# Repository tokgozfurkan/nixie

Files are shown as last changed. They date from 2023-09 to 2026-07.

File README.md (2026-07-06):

# MSF radio controlled Nixie clock project

The firmware is written, and it compiles clean for your exact chip. Here's everything you need to know.

What I built
New sketch in code/nixieClock/nixieClock/ — three files:

nixieClock.ino — the clock: RTC-driven display, MSF sync policy, anti-poisoning, watchdog, and serial diagnostics. All configuration (pin mapping, MSF pin/polarity, sync thresholds) sits in one marked block at the top.
MSFDecoder.h / MSFDecoder.cpp — a reworked decoder (Jarkman's proven pulse logic kept). Crucially, it now uses a pin-change interrupt, because your new board wires the receiver to PC3/A3, which has no INT0/INT1 — the old library literally could not have worked on this PCB. It also hands fixes to the main loop atomically and validates every field.
Your two questions
Libraries — yes, keep them. It uses exactly what you already had: Wire (built-in) and DS3231 by Andrew Wickert (v1.2.0). The MSF decoder is your own vendored source, improved. Nothing new to install except the board package.

Memory — plenty. I compiled it for real (portable arduino-cli + MiniCore in my scratchpad, nothing installed on your system): 12,824 bytes flash (39%) and 521 bytes RAM (25%) with serial diagnostics on; 9,494 / 342 bytes with serial off. Zero compiler warnings. Roughly 60% of the chip is still free.

One flashing caveat: your BOM says ATmega328PB, not 328P. Flash via MiniCore (board: ATmega328, variant: 328PB, external 16 MHz — your BOM's crystal is 16 MHz). Plain "Uno" settings will refuse the PB's device signature.

Failure cases handled
No signal / mixed signal: a fix is only trusted after fixed-bit checks, all four parity groups, calendar sanity (including days-in-month), and two consecutive frames exactly one minute apart. A corrupted frame essentially cannot pass twice consistently. Meanwhile the DS3231 keeps time — the display never depends on reception.
Summer/winter: MSF broadcasts UK civil time with BST already applied, so changeovers arrive over the air and the clock corrects itself within ~3 minutes of good reception after the switch.
RTC lost power (no battery / first boot): the DS3231's oscillator-stop flag is checked; until the first radio sync the display blinks to say "not set" instead of showing a confident wrong time.
RTC or I²C dies at runtime: the clock freewheels on the MCU crystal (~2 s/day worst case), the bus gets a timeout plus periodic re-init, and a 4-second watchdog reboots out of any hard hang.
Nixie poisoning: hourly slot-machine cycle at xx:59:45 (~13 s, every cathode), a power-on 0–9 sweep, and a 65-minute fallback cycle while unsynced.
Accuracy: the RTC is set on a whole-second boundary of the radio epoch (a few tens of ms error), and only rewritten when it drifts ≥2 s or once per day — no needless jitter.
Bring-up (in the file header too)
Flash with ENABLE_SERIAL 1, open the monitor at 115200, send h for the command list.
Send t — each tube steps 0–9 with commentary. The TUBE_PINS[][] table is my best guess; the PDFs don't reveal the U4→U1 header order, so fix the table until tubes match the commentary.
Send m — live MSF pulse widths. You should see ~100/200/300 ms off-pulses each second and 500 ms at the minute. If not: try MSF_PIN A2 (the schematic is ambiguous between PC2/PC3), or flip MSF_PULSE_ACTIVE_HIGH.
Send i anytime for full status (signal, frames accepted/rejected, last sync age).
Two hardware flags from the schematics
I couldn't find I²C pull-up resistors on the signal board's SDA/SCL (R1/R2 are LED resistors). The AVR's weak internal pull-ups often limp along, but if the RTC reads flaky, add ~4.7 kΩ to 5 V on both lines. The code tolerates and reports a bad bus either way.
The 16-pin tube header carries only signals — make sure the two boards share a ground through the single-pin headers, or the K155ID1s will see garbage levels.
Also note: if your real tube mapping turns out to use pins 0/1 (the schematic suggests PD0/PD1 do go to the header), set ENABLE_SERIAL 0 for the final flash — the UART owns those pins while serial is active.

I went back over both schematics, the BOMs, and the firmware with a critical eye. Findings below, ordered by how likely they are to actually bite you.

Likely bring-up killers (fix these first)
1. The MSF indicator LED is loading the receiver output. On the signal board, R2 (1 kΩ) + LED hang directly on the MSF net between the Canaduino /OUT and the MCU. The MAS6180C receiver IC inside that module can only source/sink about ±0.5 mA; an LED through 1 kΩ tries to pull ~3 mA, so the line will likely clamp around the LED's forward voltage (~2 V) — below the ATmega's VIH of ~3 V at 5 V. Result: the MCU may never see a HIGH and the decoder stays silent, exactly the "no signal" failure that's hardest to diagnose. Change: remove R2/LED from the signal line. Either buffer it with a small MOSFET/transistor, or (simplest) move the LED to a spare MCU pin and let the firmware mirror the MSF input onto it — a three-line code addition I can make once the pin exists.

2. No USB-C CC pull-downs on either board. Neither BOM contains 5.1 kΩ resistors, and both Type-C connectors show CC1/CC2 without terminations. Without a 5.1 kΩ pull-down on each CC pin, a USB-C source (C-to-C cable, laptop, modern charger) will never enable VBUS — the board only powers from legacy A-to-C cables. Add: 2× 5.1 kΩ (CC1, CC2) on the combined board.

3. No 100 nF decoupling on the signal board. The signal-stage BOM has only bulk capacitance (47 µF + 10 µF) — no ceramics at the ATmega's VCC/AVCC pins or at the DS3231. Sitting next to a 160 V flyback, that's an invitation for random resets and I²C corruption. Add: 100 nF at every supply pin (MCU ×2, RTC, receiver).

4. No programming or serial access. I can't find an ISP header, a UART header, a reset pull-up, or an auto-reset circuit. MOSI/MISO/SCK and RXD/TXD all appear to run off to the tube header (U4). You can technically program through U4 plus the RST pin, but it's fragile. Add on the combined board: a 6-pin ISP header, a 10 kΩ pull-up on RESET (the internal one is weak for an environment with an HV switcher), and ideally a UART header with the DTR/100 nF auto-reset — the firmware's diagnostic commands (t, m, i) are only useful if you can reach the UART. Related: route the tube BCD lines away from PD0/PD1 when you re-layout, so serial debugging never conflicts with the display (removing the whole ENABLE_SERIAL 0 caveat in the code).

5. Crystal discrepancy. The schematic footprint says "49S13.5M…" (13.5 MHz) but the BOM part is 16 MHz. Everything — millis(), the MSF pulse classification, serial baud — assumes 16 MHz. Verify what's actually soldered; the m monitor makes it obvious (100 ms pulses would read ~118 ms with a 13.5 MHz part).

Schematic improvements for the combined board
Keep the receiver far from the flyback. A 60 kHz AM receiver next to an LT3757 switcher and USB noise is the classic nixie-clock mistake. Put the ferrite antenna at the board edge farthest from the PSU (or on a short off-board lead), add an RC filter (e.g. 100 Ω + 100 µF) on the receiver's 5 V, and keep the tube BCD traces away from it.
Route the receiver's PDN pin to an MCU pin instead of tying it off. These receivers occasionally wedge their AGC; firmware could then power-cycle the receiver if no valid frame arrives for, say, 12 hours. Cheap insurance, and I can add the code for it.
I²C pull-ups and RTC battery. If "DS3231#2" is a socket for a ZS-042-style module, the module brings its own 4.7 kΩ pull-ups and a CR2032 — fine. If you move to a bare DS3231 chip on the combined board, you must add the pull-ups, VBAT with a coin cell, and a 100 nF. Without a battery, every power cut means a blinking display until the first radio fix (~3 min at best).
Optionally route DS3231's SQW to the MCU (with a pull-up — it's open-drain). A hardware 1 Hz tick is nicer than polling if you ever add a seconds display or a blinking colon.
Consider an INS-1 neon colon between tubes 2 and 3 (spare MCU pin + high-voltage transistor + ~220 kΩ from 160 V). Cosmetic, but it also gives a visible "alive" heartbeat.
Ground between the boards: the 16-pin tube header carries no GND, so the prototype pair depends entirely on the single-pin jumpers. Add several ground pins next to the signal lines (or just let the combined board solve it).
Flyback margins: the IRLR3110 (100 V) sees 5 V + ~16 V reflected + the leakage-inductance spike, and there's no snubber. The DA2032 has low leakage so it's probably fine, but scope the drain on first power-up; add an RC snubber footprint just in case. The feedback divider (1 M + pot) doubles as an HV bleeder, which is good. Add an HV warning on the silkscreen.
Two things that look wrong but are actually fine: the K155ID1's TTL inputs float HIGH when the MCU resets or the header is unplugged, which reads as BCD 15 → tubes blank during reset/programming — a happy accident worth keeping; and the 10 k anode resistors give ~2 mA per IN-12A, slightly conservative but adjustable via the pot.
Code improvements
Honest self-review of nixieClock.ino and the decoder:

Add the MSF activity LED mirror (one output pin, set in handleEdge or the display loop) once the hardware LED moves off the signal line — restores the blink-per-second feedback the board intended, without loading the receiver.
Add receiver power-cycling via PDN if you route it: "no confirmed fix in 12 h → pulse PDN" plus a counter in the status output.
RTC reads are 6 separate I²C transactions every 500 ms. Works, but a single burst read of registers 0x00–0x06 would be more atomic (no risk of reading minutes just as they roll over — currently a roll-over between getMinute() and getHour() could produce a one-off time that's wrong by an hour for half a second; the next 500 ms poll self-corrects, and the display only shows HH:MM, but a burst read removes the race entirely). This is the one genuine, if minor, correctness improvement I'd make in the current code.
applyFix blocks up to ~1 s spinning to the second boundary. Documented and harmless (sync happens at most daily), but if you ever add a seconds display it should become non-blocking.
Leap seconds are handled by rejection: a 61-bit minute fails the bitIndex == 60 check, the frame is discarded, and the next minute syncs normally. No change needed — just noting it's covered.
PULSE_OFF_OFFSET 20 is tuned for Jarkman's 2011 receiver, not the Canaduino. Use the m monitor on real hardware: if the off-widths cluster at, say, 95/195/295 you can drop it to 0. Worth re-checking rather than trusting the inherited constant.
Optional feature, since you skipped night blanking: duty-cycle dimming is nearly free with the K155ID1 (alternate digit/TUBE_BLANK at a few hundred Hz), which would allow night dimming and extend tube life without fully blanking.
The one thing I'd remove: nothing in the firmware, but on the hardware side the second USB-C connector disappears in the combined design, and R2+LED should come off the MSF line as described.

If you want, I can implement the firmware-side items now (burst RTC read, LED mirror pin, PDN control behind a #define so they're inert until the hardware exists) — say the word.

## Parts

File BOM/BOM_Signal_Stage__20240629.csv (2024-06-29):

LCSC Part Number | Manufacture Part Number | Manufacturer | Customer NO. | Package | Description | RoHS | Order Qty. | Min\Mult Order Qty. | Unit Price($) | Order Price($)
C2875465 | 0603N220J500CT | Walsin Tech Corp |  | 0603 | 50V 22pF NP0 ±5% 0603 Multilayer Ceramic Capacitors MLCC - SMD/SMT ROHS | YES | 100 | 100\100 | 0.003 | 0.30
C7496820 | F.0603.00139/P2-0603R1TS2-06T-002 | TUOZHAN |  | 0603 | 5mA -40℃~+85℃ Red 120° 0603 Light Emitting Diodes (LED) ROHS | YES | 100 | 100\100 | 0.0032 | 0.32
C132230 | ATMEGA328PB-AU | Microchip Tech |  | TQFP-32(7x7) | 32KB 1.8V~5.5V AVR 2KB 20MHz FLASH 27 TQFP-32(7x7) Microcontroller Units (MCUs/MPUs/SOCs) ROHS | YES | 2 | 1\1 | 1.8028 | 3.61
C5265724 | HY16M49SOB2T02 | Huiyuan crystal |  | HC-49S | 16MHz 20pF ±20ppm ±50ppm HC-49S Crystals ROHS | YES | 10 | 10\10 | 0.0342 | 0.34
C2907113 | FRC0603J102 TS | FOJAN |  | 0603 | 100mW Thick Film Resistors 75V ±100ppm/℃ ±5% 1kΩ 0603 Chip Resistor - Surface Mount ROHS | YES | 100 | 100\100 | 0.0008 | 0.08
C5146764 | X5511FV-04-C30D743-0743 | XKB Connection |  | - | 2.54mm Plugin 4P 1x4P 3mm Circular Holes - Female Headers ROHS | YES | 10 | 5\5 | 0.0715 | 0.72

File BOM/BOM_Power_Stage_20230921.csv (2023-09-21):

LCSC Part Number | Manufacture Part Number | Manufacturer | Customer NO. | Package | Description | RoHS | Order Qty. | Min\Mult Order Qty. | Unit Price | Order Price
C382228 | FM31X223K631EEG | PSA(Prosperity Dielectrics) |  | 1206 | 630V 22nF X7R ±10% 1206 Multilayer Ceramic Capacitors MLCC - SMD/SMT ROHS | YES | 50 | 50\50 | 0.008400 | 0.42
C976240 | FM31X224K251EEG | PSA(Prosperity Dielectrics) |  | 1206 | 250V 220nF ±10% 1206 Multilayer Ceramic Capacitors MLCC - SMD/SMT ROHS | YES | 20 | 20\20 | 0.020000 | 0.40
C1884 | 1206CG101J500NT | FH (Guangdong Fenghua Advanced Tech) |  | 1206 | 50V 100pF C0G ±5% 1206 Multilayer Ceramic Capacitors MLCC - SMD/SMT ROHS | YES | 50 | 50\50 | 0.011500 | 0.58
C7467448 | FRL2512JR020TS | FOJAN |  | 2512 | 1W Thick Film Resistors 1200ppm/℃ ±5% 20mΩ 2512 Chip Resistor - Surface Mount ROHS | YES | 10 | 10\10 | 0.039000 | 0.39
C67277 | IRLR3110ZTRPBF | Infineon Technologies |  | TO-252-2(DPAK) | 100V 42A 140W 14mΩ@10V,38A N Channel TO-252-2(DPAK) MOSFETs ROHS | YES | 10 | 1\1 | 0.989600 | 9.90
C464972 | FN31X104K500PXG | PSA(Prosperity Dielectrics) |  | 1206 | 50V 100nF X7R ±10% 1206 Multilayer Ceramic Capacitors MLCC - SMD/SMT ROHS | YES | 50 | 50\50 | 0.006100 | 0.31
C229316 | AC1206FR-07140KL | YAGEO |  | 1206 | 250mW Thick Film Resistors ±100ppm/℃ ±1% 140kΩ 1206 Chip Resistor - Surface Mount ROHS | YES | 50 | 50\50 | 0.004400 | 0.22
C2918513 | CS3225X5R476K160NRL | Samwha Capacitor |  | 1210 | 16V 47uF X5R ±10% 1210 Multilayer Ceramic Capacitors MLCC - SMD/SMT ROHS | YES | 25 | 5\5 | 0.095800 | 2.40
C280037 | CR-06JL7----1M | Viking Tech |  | 1206 | 250mW Thick Film Resistors ±5% 1MΩ 1206 Chip Resistor - Surface Mount ROHS | YES | 50 | 50\50 | 0.002400 | 0.12
C280031 | CR-06JL7----0R | Viking Tech |  | 1206 | 250mW Thick Film Resistors ±5% 0Ω 1206 Chip Resistor - Surface Mount ROHS | YES | 50 | 50\50 | 0.002400 | 0.12
C93059 | 1206X106M250NT | FH (Guangdong Fenghua Advanced Tech) |  | 1206 | 25V 10uF X5R ±20% 1206 Multilayer Ceramic Capacitors MLCC - SMD/SMT ROHS | YES | 10 | 10\10 | 0.017900 | 0.18
C128545 | VG039NCHXTB104 | HDK(Hokuriku Elec Industry) |  | SMD | ±25% 100kΩ SMD Variable Resistors/Potentiometers ROHS | YES | 10 | 10\10 | 0.079500 | 0.80
C5274471 | KH-SS12F44-G3.5 | Shenzhen Kinghelm Elec |  | Plugin | Plugin Slide Switches ROHS | YES | 10 | 10\10 | 0.023100 | 0.23
C104602 | RTT06103JTP | RALEC |  | 1206 | 250mW ±100ppm/℃ ±5% 10kΩ 1206 Chip Resistor - Surface Mount ROHS | YES | 100 | 100\100 | 0.002200 | 0.22
C456012 | TYPE-C 6P | SHOU HAN |  | SMD | 1 Surface Mount 6P Female -40℃~+85℃ Type-C SMD USB Connectors ROHS | YES | 10 | 10\10 | 0.043600 | 0.44
C881297 | CR1206J22R0P05Z | Ever Ohms Tech |  | 1206 | 250mW ±100ppm/℃ ±5% 22Ω 1206 Chip Resistor - Surface Mount ROHS | YES | 50 | 50\50 | 0.002300 | 0.12
C962640 | RFN1LAM6STR | ROHM Semicon |  | SOD-128 | 1.15V@800mA 25ns Single 800mA 600V SOD-128 Diodes - Fast Recovery Rectifiers ROHS | YES | 10 | 1\1 | 0.087900 | 0.88
C81276 | C81276 | BOOMELE(Boom Precision Elec) |  | Plugin,P=2.54mm | Straight 1P Plugin Black Plugin,P=2.54mm Pin Headers ROHS | YES | 100 | 100\100 | 0.006600 | 0.66
C5153981 | FRC1206F6342TS | FOJAN |  | 1206 | 250mW Thick Film Resistors ±100ppm/℃ ±1% 63.4kΩ 1206 Chip Resistor - Surface Mount ROHS | YES | 10 | 5\5 | 0.002900 | 0.03

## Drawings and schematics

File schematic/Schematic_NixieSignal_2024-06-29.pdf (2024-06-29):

A | A
B | B

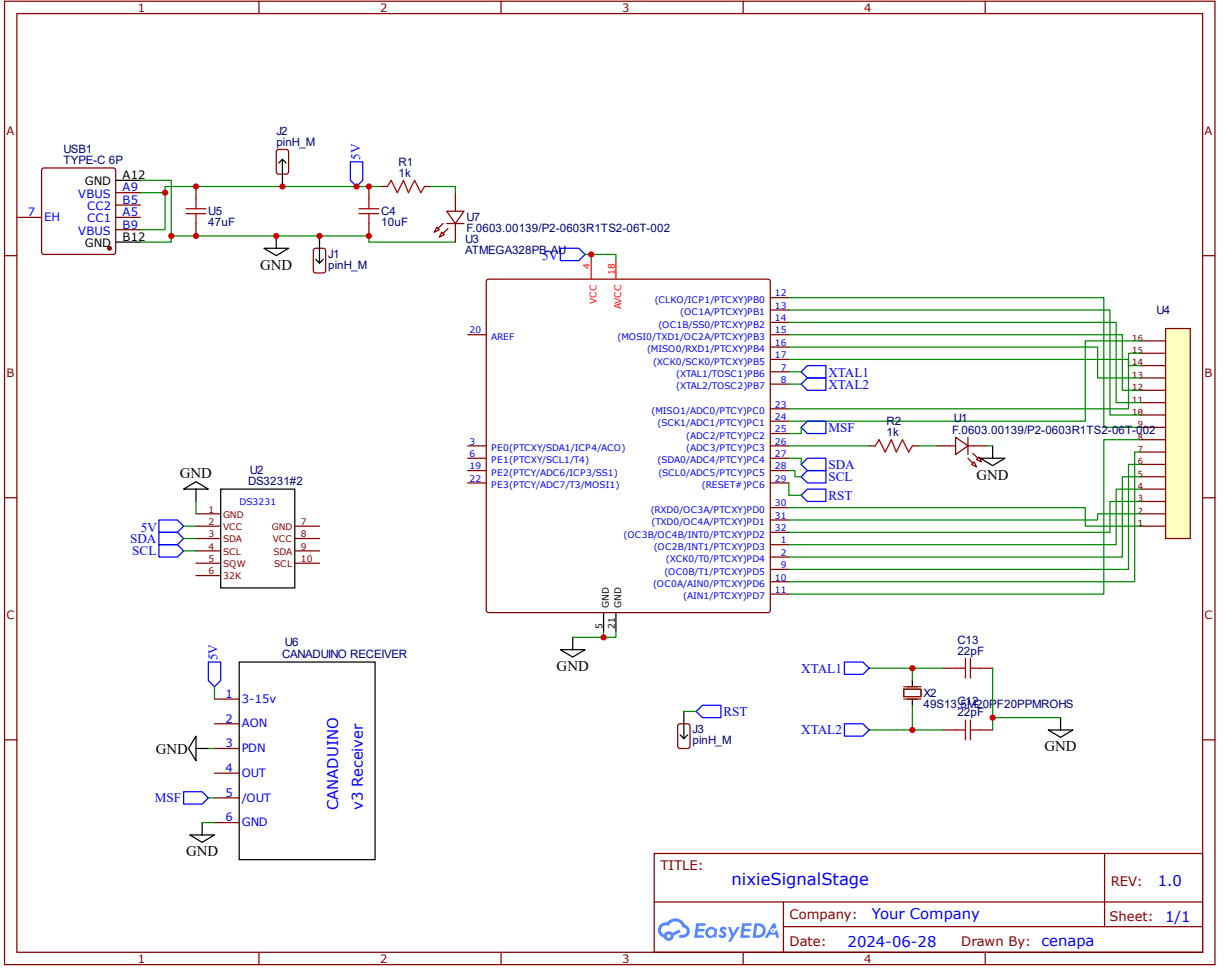
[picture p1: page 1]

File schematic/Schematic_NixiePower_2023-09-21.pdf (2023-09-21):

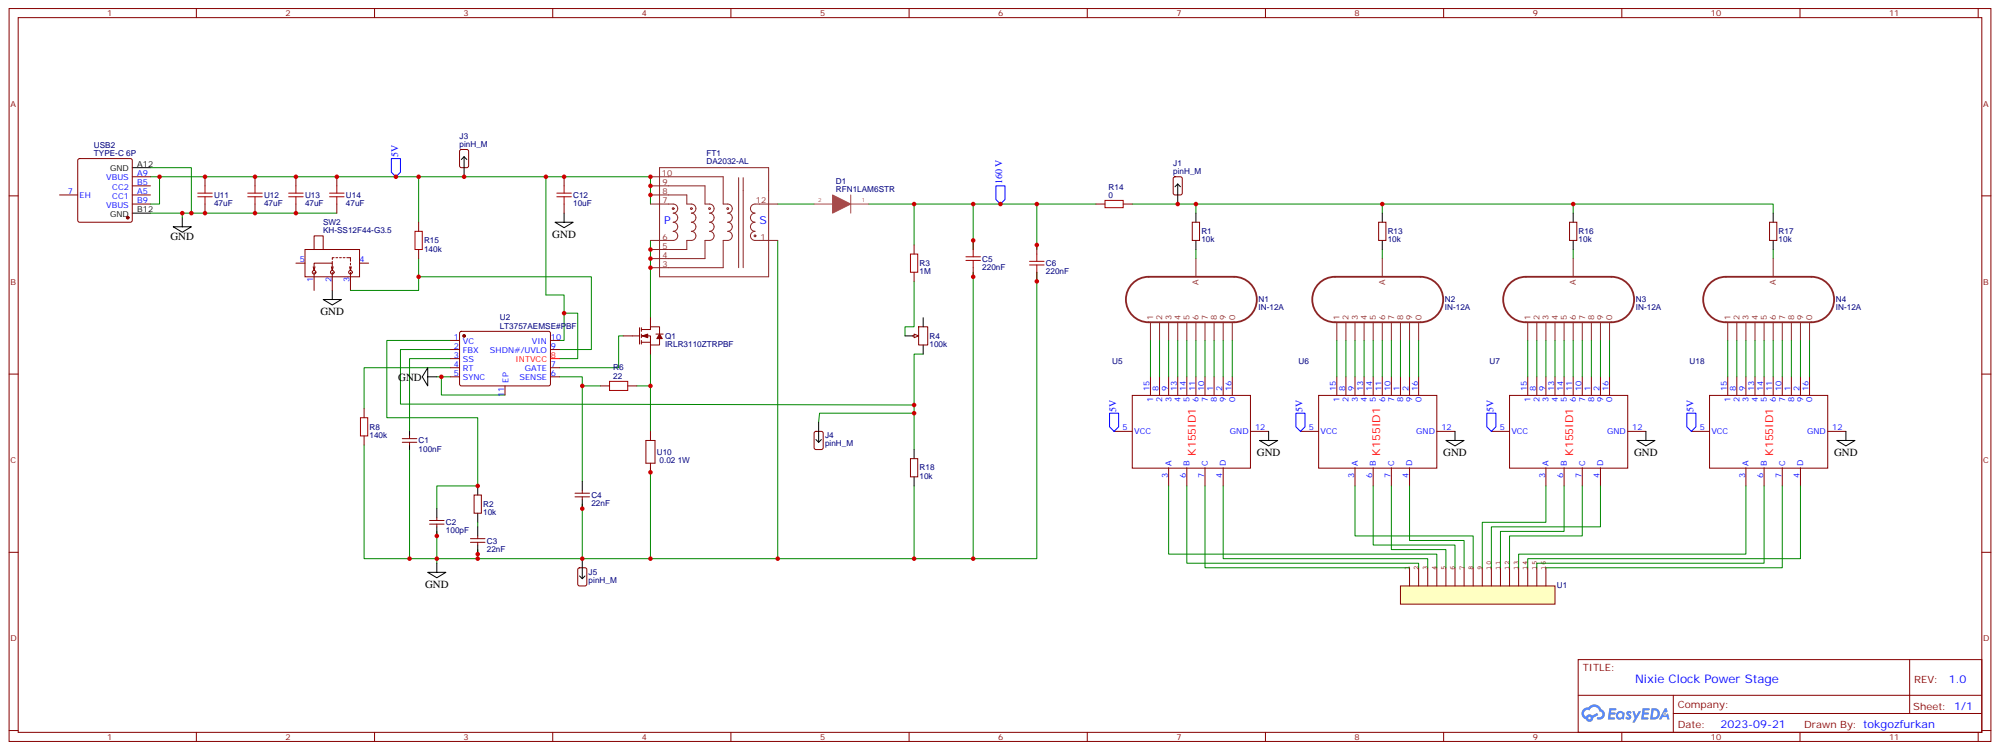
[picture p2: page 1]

10

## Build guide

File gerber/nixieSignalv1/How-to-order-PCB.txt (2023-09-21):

How to Order PCB

Please refer to:
https://docs.easyeda.com/en/PCB/Order-PCB

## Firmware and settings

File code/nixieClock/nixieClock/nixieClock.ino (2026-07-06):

/*
  nixieClock — MSF-synchronised IN-12A nixie clock
  =================================================

  Hardware (this repo):
    * Signal board: ATmega328PB @ 16 MHz, DS3231 RTC on I2C (A4/A5),
      Canaduino v3 MSF receiver with its inverted /OUT wired to the MCU
      (assumed A3/PC3 — see MSF_PIN), 16-pin header carrying 4x4 BCD
      lines to the power board.
    * Power board: LT3757 flyback boost to 160 V, 4x IN-12A tubes, each
      behind a K155ID1 BCD decoder. Any BCD input > 9 blanks that tube,
      which this code uses for blanking (TUBE_BLANK).

  Behaviour:
    * The DS3231 is the timekeeper; the display is always driven from it.
    * The MSF decoder runs continuously via a pin-change interrupt. A time
      fix is only trusted after: fixed-bit check + all four parity groups
      + calendar sanity + TWO consecutive frames exactly one minute apart
      (defeats corrupted/mixed reception). The RTC is then set to within
      a few tens of ms of the radio second.
    * The RTC is only rewritten when it disagrees with the radio by >= 2 s
      or at most once per 24 h. Summer/winter changes arrive over the air
      (MSF broadcasts UK civil time) and are corrected within ~3 minutes
      of good reception after the change.
    * If the RTC stops responding, the clock freewheels on the MCU crystal
      (~20 ppm) until it returns. If the time has never been trusted (RTC
      lost power and no radio sync yet) the display blinks while counting,
      to say "not set".
    * Anti-poisoning: once per hour at xx:59:45 a ~13 s slot-machine cycle
      exercises every cathode of every tube; a fallback cycle runs every
      65 min if the time is not set.
    * A 4 s watchdog recovers from any hang; I2C has a bus timeout.

  Flashing (IMPORTANT — the chip is an ATmega328PB, not a plain 328P):
    * Install MiniCore in the Arduino IDE boards manager:
      https://mcudude.github.io/MiniCore/package_MCUdude_MiniCore_index.json
    * Board: ATmega328 / Variant: 328PB / Clock: external 16 MHz.
    * Libraries: Wire (built in) and "DS3231" by Andrew Wickert
      (NorthernWidget) — the same one the earlier sketches used.

  Bring-up checklist:
    1. Flash with ENABLE_SERIAL 1, open Serial Monitor @ 115200, send 'h'.
    2. Send 't': each tube steps through 0..9 with serial commentary.
       Correct TUBE_PINS[][] below until the tubes match the commentary.
    3. Send 'm': raw MSF pulse monitor. With reception you should see one
       off-pulse per second near 100/200/300 ms (500 ms once a minute).
       If the widths look inverted (~700-900 ms), flip
       MSF_PULSE_ACTIVE_HIGH. If nothing arrives, try MSF_PIN A2 — the
       schematic is ambiguous between PC2 and PC3.
    4. Give it 2-5 min of good reception: you should see "MSF frame ok"
       and then "RTC set from MSF".
    5. If your final TUBE_PINS mapping uses pins 0/1 (the UART pins), set
       ENABLE_SERIAL 0 for the production flash — while serial is enabled
       the UART owns those pins and two BCD lines would misbehave.
*/

#include <Wire.h>
#include <DS3231.h>
#include <avr/wdt.h>
#include "MSFDecoder.h"

// ============================ CONFIGURATION ============================

#define ENABLE_SERIAL   1       // set 0 for the final flash if TUBE_PINS uses pins 0/1
#define ENABLE_WATCHDOG 1       // needs a modern bootloader (MiniCore is fine)
#define SERIAL_BAUD     115200

#define MSF_PIN               A3    // PC3 per schematic; try A2 if silent
#define MSF_PULSE_ACTIVE_HIGH true  // /OUT: HIGH while the carrier is off
// If you move MSF_PIN off the A0-A5 port, also change MSF_PCINT_VECTOR
// in MSFDecoder.h (PCINT0_vect for D8-D13, PCINT2_vect for D0-D7).

// MCU pin -> K155ID1 BCD input mapping, one row per tube, left to right.
// Columns are {A, B, C, D} = binary weights {1, 2, 4, 8} (K155ID1 pins
// 3, 6, 7, 4). *** BEST GUESS — verify with the 't' serial command and
// edit this table until the tubes match the commentary. ***
const uint8_t TUBE_PINS[4][4] = {
  {  8,  9, 10, 11 }, // tube 1: hour tens    (PB0..PB3)
  { 12, 13, A0, A1 }, // tube 2: hour units   (PB4, PB5, PC0, PC1)
  {  0,  1,  2,  3 }, // tube 3: minute tens  (PD0..PD3)
  {  4,  5,  6,  7 }, // tube 4: minute units (PD4..PD7)
};

#define TUBE_BLANK 0x0F  // any BCD value > 9 turns all K155ID1 outputs off

const int32_t  SYNC_THRESHOLD_S    = 2;              // rewrite RTC if off by this much
const uint32_t RESYNC_INTERVAL_MS  = 86400000UL;     // ... or at least daily
const uint8_t  POISON_MINUTE       = 59;             // hourly cycle at xx:59:45
const uint8_t  POISON_SECOND      = 45;
const uint32_t POISON_DURATION_MS  = 13000UL;
const uint32_t POISON_FALLBACK_MS  = 65UL * 60UL * 1000UL; // if time never set

// =======================================================================

DS3231     rtc;
MSFDecoder msf;

struct ClockTime
{
  uint8_t y;   // 0-99 (20xx)
  uint8_t mo;  // 1-12
  uint8_t d;   // 1-31
  uint8_t h;   // 0-23
  uint8_t mi;  // 0-59
  uint8_t s;   // 0-59
};

// The "soft clock": a RAM copy of the current time, re-anchored from the
// RTC every 500 ms and ticked from millis() so it freewheels if the RTC
// or the I2C bus dies.
ClockTime     softTime = {0, 1, 1, 0, 0, 0};
unsigned long softAnchor = 0;

bool    rtcResponding = false;  // recent I2C reads succeeded
bool    rtcTrusted    = false;  // responding AND oscillator-stop flag clear
uint8_t rtcFailCount  = 0;

bool          everSynced    = false;  // at least one MSF sync this power-up
unsigned long lastSyncMillis = 0;

bool          havePrevFix   = false;  // MSF double-frame confirmation chain
uint32_t      prevFixMin    = 0;
unsigned long prevFixMillis = 0;

bool          poisonActive     = false;
unsigned long poisonStart      = 0;
unsigned long lastPoisonMillis = 0;

// ---------------------------- date helpers ----------------------------
// Valid for 2000-2099 (every year divisible by 4 is a leap year there).

uint8_t daysInMonth(uint8_t y, uint8_t mo)
{
  static const uint8_t dim[12] = {31, 28, 31, 30, 31, 30, 31, 31, 30, 31, 30, 31};
  uint8_t n = dim[mo - 1];
  if (mo == 2 && (y & 3) == 0) n++;
  return n;
}

uint16_t days2000(uint8_t y, uint8_t mo, uint8_t d)
{
  static const uint16_t cum[12] = {0, 31, 59, 90, 120, 151, 181, 212, 243, 273, 304, 334};
  uint16_t days = (uint16_t)y * 365 + (y + 3) / 4 + cum[mo - 1] + (d - 1);
  if (mo > 2 && (y & 3) == 0) days++;
  return days;
}

uint32_t minutes2000(const MSFTime &f)
{
  return (uint32_t)days2000(f.year, f.month, f.day) * 1440UL
       + (uint32_t)f.hour * 60UL + f.minute;
}

uint32_t secs2000(const ClockTime &t)
{
  return (uint32_t)days2000(t.y, t.mo, t.d) * 86400UL
       + (uint32_t)t.h * 3600UL + (uint32_t)t.mi * 60UL + t.s;
}

void addSeconds(ClockTime &t, uint32_t secs)
{
  uint32_t v = t.s + secs;
  t.s = v % 60; v /= 60;
  v += t.mi;
  t.mi = v % 60; v /= 60;
  v += t.h;
  t.h = v % 24; v /= 24;
  while (v--)
  {
    if (++t.d > daysInMonth(t.y, t.mo))
    {
      t.d = 1;
      if (++t.mo > 12) { t.mo = 1; if (++t.y > 99) t.y = 0; }
    }
  }
}

// ---------------------------- tube driving ----------------------------

void setTube(uint8_t tube, uint8_t value)
{
  for (uint8_t b = 0; b < 4; b++)
    digitalWrite(TUBE_PINS[tube][b], (value >> b) & 1);
}

void blankAll()
{
  for (uint8_t t = 0; t < 4; t++) setTube(t, TUBE_BLANK);
}

void showTime(uint8_t h, uint8_t mi)
{
  setTube(0, h / 10);
  setTube(1, h % 10);
  setTube(2, mi / 10);
  setTube(3, mi % 10);
}

// ------------------------------- RTC ----------------------------------

bool timeValid()
{
  // Trust the RTC when its oscillator never stopped; if the RTC has died
  // but we synced from the radio this power-up, the freewheeling soft
  // clock is still good.
  return rtcTrusted || (everSynced && !rtcResponding);
}

bool readRTC(ClockTime &t)
{
  bool h12, pm, century;
  t.s  = rtc.getSecond();
  t.mi = rtc.getMinute();
  t.h  = rtc.getHour(h12, pm);
  t.d  = rtc.getDate();
  t.mo = rtc.getMonth(century);
  t.y  = rtc.getYear();
  // A dead/absent bus yields out-of-range BCD; treat anything insane as a
  // failed read so the soft clock freewheels instead of jumping.
  if (t.s > 59 || t.mi > 59 || t.h > 23 || t.y > 99) return false;
  if (t.mo < 1 || t.mo > 12 || t.d < 1 || t.d > daysInMonth(t.y, t.mo)) return false;
  return true;
}

void serviceRTC(bool force)
{
  static unsigned long last = 0;
  if (!force && millis() - last < 500UL) return;
  last = millis();

  ClockTime t;
  if (readRTC(t))
  {
    rtcFailCount  = 0;
    rtcResponding = true;
    rtcTrusted    = rtc.oscillatorCheck(); // false if the RTC ever lost power
    softTime      = t;
    softAnchor    = millis();
  }
  else
  {
    if (rtcFailCount < 250) rtcFailCount++;
    if (rtcFailCount >= 6) { rtcResponding = false; rtcTrusted = false; }
    if (rtcFailCount % 20 == 0)
    {
      Wire.begin(); // try to recover a wedged bus
#if defined(WIRE_HAS_TIMEOUT)
      Wire.setWireTimeout(25000, true);
      Wire.clearWireTimeoutFlag();
#endif
    }
  }
}

void serviceSoftClock()
{
  while (millis() - softAnchor >= 1000UL)
  {
    softAnchor += 1000UL;
    addSeconds(softTime, 1);
  }
}

// ------------------------------- MSF ----------------------------------

#if ENABLE_SERIAL
void print2(uint8_t v)
{
  if (v < 10) Serial.print('0');
  Serial.print(v);
}

void printClock(const ClockTime &t)
{
  Serial.print(F("20")); print2(t.y);
  Serial.print('-'); print2(t.mo);
  Serial.print('-'); print2(t.d);
  Serial.print(' '); print2(t.h);
  Serial.print(':'); print2(t.mi);
  Serial.print(':'); print2(t.s);
}
#endif

// Write a confirmed radio fix into the RTC, aligned to the second.
void applyFix(const MSFTime &f, unsigned long fixMillis)
{
  // Spin (max ~1 s) to a whole-second boundary of the radio epoch so the
  // DS3231's internal second-countdown restarts in phase with the signal.
  unsigned long el;
  do {
#if ENABLE_WATCHDOG
    wdt_reset();
#endif
    el = millis() - fixMillis;
  } while (el % 1000UL > 30UL);

  ClockTime t = { f.year, f.month, f.day, f.hour, f.minute, 0 };
  uint16_t d0 = days2000(t.y, t.mo, t.d);
  addSeconds(t, el / 1000UL);
  uint8_t dow = (f.dow + (uint8_t)(days2000(t.y, t.mo, t.d) - d0)) % 7;

  rtc.setClockMode(false); // 24 h
  rtc.setYear(t.y);
  rtc.setMonth(t.mo);
  rtc.setDate(t.d);
  rtc.setDoW(dow + 1);     // 1 = Sunday
  rtc.setHour(t.h);
  rtc.setMinute(t.mi);
  rtc.setSecond(t.s);      // written last; also clears the oscillator-stop flag

  softTime   = t;
  softAnchor = millis() - (el % 1000UL);

#if ENABLE_SERIAL
  Serial.print(F("RTC set from MSF: "));
  printClock(t);
  Serial.println(f.summer ? F(" (BST)") : F(" (GMT)"));
#endif
}

void serviceMSF()
{
  MSFTime f;
  unsigned long tf;
  if (!msf.takeFix(f, tf)) return;

  uint32_t fixMin = minutes2000(f);

  // Require two consecutive frames exactly one minute apart before
  // touching the RTC — a corrupted frame that beat the parity checks
  // will practically never do so twice in a row *and* be consistent.
  bool confirmed = false;
  if (havePrevFix)
  {
    unsigned long gap = tf - prevFixMillis;
    confirmed = (gap >= 59000UL && gap <= 61000UL) && (fixMin == prevFixMin + 1);
  }
  havePrevFix   = true;
  prevFixMin    = fixMin;
  prevFixMillis = tf;

#if ENABLE_SERIAL
  Serial.print(F("MSF frame ok: 20")); print2(f.year);
  Serial.print('-'); print2(f.month);
  Serial.print('-'); print2(f.day);
  Serial.print(' '); print2(f.hour);
  Serial.print(':'); print2(f.minute);
  Serial.println(confirmed ? F(" [confirmed]") : F(" [waiting for 2nd frame]"));
#endif

  if (!confirmed) return;

  uint32_t msfNow = fixMin * 60UL + (millis() - tf) / 1000UL;
  int32_t  diff   = (int32_t)(msfNow - secs2000(softTime));

  bool need = !timeValid()
           || diff >= SYNC_THRESHOLD_S || diff <= -SYNC_THRESHOLD_S
           || !everSynced
           || (millis() - lastSyncMillis) >= RESYNC_INTERVAL_MS;
  if (need) applyFix(f, tf);

  // Even when no rewrite was needed, the radio just vouched for the RTC.
  everSynced     = true;
  lastSyncMillis = millis();
}

// --------------------------- anti-poisoning ---------------------------

void startPoison()
{
  poisonActive = true;
  poisonStart  = millis();
}

void servicePoison()
{
  if (poisonActive)
  {
    if (millis() - poisonStart >= POISON_DURATION_MS)
    {
      poisonActive     = false;
      lastPoisonMillis = millis();
    }
    return;
  }
  if (timeValid() && softTime.mi == POISON_MINUTE && softTime.s == POISON_SECOND)
    startPoison();
  else if (millis() - lastPoisonMillis >= POISON_FALLBACK_MS)
    startPoison(); // keeps cathodes exercised even while unsynchronised
}

// ------------------------------ display -------------------------------

void serviceDisplay()
{
  if (poisonActive)
  {
    uint16_t step = (uint16_t)((millis() - poisonStart) / 70UL);
    for (uint8_t t = 0; t < 4; t++)
      setTube(t, (step + t * 3) % 10);
    return;
  }

  bool show = true;
  if (!timeValid()) show = (millis() % 1000UL) < 700UL; // blink = "not set"

  if (show) showTime(softTime.h, softTime.mi);
  else      blankAll();
}

// ------------------------- serial diagnostics -------------------------

#if ENABLE_SERIAL

void printHelp()
{
  Serial.println(F("Commands: i=status  t=tube mapping test  m=MSF pulse monitor (30s)  p=poison cycle now  h=help"));
}

void printStatus()
{
  Serial.println(F("--- nixieClock status ---"));
  Serial.print(F("Soft time : ")); printClock(softTime); Serial.println();
  Serial.print(F("Time valid: ")); Serial.println(timeValid() ? F("yes") : F("no (display blinking)"));
  Serial.print(F("RTC       : "));
  Serial.print(rtcResponding ? F("responding") : F("NOT RESPONDING"));
  Serial.print(F(", oscillator "));
  Serial.println(rtcTrusted ? F("ok") : F("stopped at some point (untrusted until sync)"));
  Serial.print(F("MSF       : signal "));
  Serial.print(msf.hasSignal() ? F("yes") : F("NO"));
  Serial.print(F(", frame bit ")); Serial.print(msf.bitCount());
  Serial.print(F(", valid frames ")); Serial.print(msf.goodFixes());
  Serial.print(F(", rejected ")); Serial.println(msf.rejects());
  Serial.print(F("Last sync : "));
  if (everSynced)
  {
    Serial.print((millis() - lastSyncMillis) / 60000UL);
    Serial.println(F(" min ago"));
  }
  else Serial.println(F("never (this power-up)"));
}

// Steps every tube through 0..9 so TUBE_PINS[][] can be verified.
void tubeTest()
{
  while (Serial.available()) Serial.read();
  Serial.println(F("Tube mapping test — press any key to abort."));
  for (uint8_t t = 0; t < 4 && !Serial.available(); t++)
  {
    blankAll();
    for (uint8_t v = 0; v < 10 && !Serial.available(); v++)
    {
      setTube(t, v);
      Serial.print(F("Tube ")); Serial.print(t + 1);
      Serial.print(F(" (row ")); Serial.print(t);
      Serial.print(F(" of TUBE_PINS) should show ")); Serial.println(v);
      unsigned long t0 = millis();
      while (millis() - t0 < 800UL && !Serial.available())
      {
#if ENABLE_WATCHDOG
        wdt_reset();
#endif
      }
    }
  }
  while (Serial.available()) Serial.read();
  blankAll();
  Serial.println(F("Test done. If digits were wrong, edit TUBE_PINS[][] and reflash."));
}

// Prints every classified MSF pulse for 30 s.
void msfMonitor()
{
  while (Serial.available()) Serial.read();
  Serial.println(F("MSF pulse monitor for 30 s (off ~100/200/300, 500=minute marker) — any key to abort."));
  uint16_t lastCount;
  noInterrupts(); lastCount = msf.dbgPulseCount; interrupts();
  unsigned long t0 = millis();
  while (millis() - t0 < 30000UL && !Serial.available())
  {
#if ENABLE_WATCHDOG
    wdt_reset();
#endif
    int16_t off, on;
    uint16_t count;
    noInterrupts();
    off = msf.dbgOffWidth; on = msf.dbgOnWidth; count = msf.dbgPulseCount;
    interrupts();
    if (count != lastCount)
    {
      lastCount = count;
      Serial.print(F("off=")); Serial.print(off);
      Serial.print(F(" ms, on=")); Serial.print(on);
      Serial.print(F(" ms, frame bit ")); Serial.println(msf.bitCount());
    }
  }
  while (Serial.available()) Serial.read();
  Serial.println(F("Monitor done."));
}

void serviceSerial()
{
  if (!Serial.available()) return;
  char c = Serial.read();
  switch (c)
  {
    case 'i': printStatus(); break;
    case 't': tubeTest();    break;
    case 'm': msfMonitor();  break;
    case 'p': startPoison(); break;
    case 'h':
    case '?': printHelp();   break;
    default:  break; // ignore line endings etc.
  }
}

#endif // ENABLE_SERIAL

// ------------------------------- setup --------------------------------

void setup()
{
  MCUSR = 0;      // make sure a watchdog reset can't turn into a boot loop
  wdt_disable();

  for (uint8_t t = 0; t < 4; t++)
    for (uint8_t b = 0; b < 4; b++)
      pinMode(TUBE_PINS[t][b], OUTPUT);
  blankAll();

#if ENABLE_SERIAL
  Serial.begin(SERIAL_BAUD);
  Serial.println(F("nixieClock starting"));
  printHelp();
#endif

  Wire.begin();
#if defined(WIRE_HAS_TIMEOUT)
  Wire.setWireTimeout(25000, true); // never let a stuck bus hang the loop
#endif

  msf.begin(MSF_PIN, MSF_PULSE_ACTIVE_HIGH);

  // power-on sweep: proves every cathode of every tube works
  for (uint8_t v = 0; v < 10; v++)
  {
    for (uint8_t t = 0; t < 4; t++) setTube(t, v);
    delay(180);
  }
  blankAll();

  softAnchor       = millis();
  lastPoisonMillis = millis();
  serviceRTC(true); // adopt battery-backed RTC time immediately if sane

#if ENABLE_SERIAL
  Serial.print(F("Boot time from RTC: "));
  printClock(softTime);
  Serial.println(rtcTrusted ? F(" (trusted)") : F(" (NOT trusted — waiting for MSF)"));
#endif

#if ENABLE_WATCHDOG
  wdt_enable(WDTO_4S);
#endif
}

void loop()
{
#if ENABLE_WATCHDOG
  wdt_reset();
#endif
  serviceSoftClock();
  serviceRTC(false);
  serviceMSF();
  servicePoison();
  serviceDisplay();
#if ENABLE_SERIAL
  serviceSerial();
#endif
}

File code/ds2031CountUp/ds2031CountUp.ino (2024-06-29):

/*

Sets the time from input and prints back time stamps for 5 seconds

Based on DS3231_set.pde
by Eric Ayars
4/11

Added printing back of time stamps and increased baud rate
(to better synchronize computer and RTC)
Andy Wickert
5/15/2011

Clean for SAMD arch, add explanation, respect code-style and
fix interpretation of Serial input if used more than once
Olivier Staquet
4/26/2020

*/

#include <DS3231.h>
#include <Wire.h>

DS3231 myRTC;

byte year;
byte month;
byte date;
byte dow;
byte hour;
byte minute;
byte second;

bool century = false;
bool h12Flag;
bool pmFlag;

// Nixie tube pins
int segmentPins[1][4] = {
  {11,10,9,8},   // Tube 1
};

// Nixie tube table
boolean segments[10][4] = {
  {0, 0, 0, 0}, // 0
  {0, 0, 0, 1}, // 1
  {0, 0, 1, 0}, // 2
  {0, 0, 1, 1}, // 3
  {0, 1, 0, 0}, // 4
  {0, 1, 0, 1}, // 5
  {0, 1, 1, 0}, // 6
  {0, 1, 1, 1}, // 7
  {1, 0, 0, 0}, // 8
  {1, 0, 0, 1}  // 9
};

/*****************************************************************************************************
 * Setup
 *  - Open Serial and Wire connection
 *  - Explain to the user how to use the program
 *****************************************************************************************************/
void setup() {
  // Start the serial port
  Serial.begin(9600);

  // Nixie tube pins
  for (int i = 0; i < 1; i++) {
    for (int j = 0; j < 4; j++) {
      pinMode(segmentPins[i][j], OUTPUT);
    }
  }
  
  // Start the I2C interface
  Wire.begin();

  // Request the time correction on the Serial
  delay(4000);
  Serial.println("Format YYMMDDwhhmmssx");
  Serial.println("Where YY = Year (ex. 20 for 2020)");
  Serial.println("      MM = Month (ex. 04 for April)");
  Serial.println("      DD = Day of month (ex. 09 for 9th)");
  Serial.println("      w  = Day of week from 1 to 7, 1 = Sunday (ex. 5 for Thursday)");
  Serial.println("      hh = hours in 24h format (ex. 09 for 9AM or 21 for 9PM)");
  Serial.println("      mm = minutes (ex. 02)");
  Serial.println("      ss = seconds (ex. 42)");
  Serial.println("Example for input : 2004095090242x");
  Serial.println("-----------------------------------------------------------------------------");
  Serial.println("Please enter the current time to set on DS3231 ended by 'x':");
}

/*****************************************************************************************************
 * Loop
 *  - Each time we receive the time correction on the Serial
 *  - Set the clock of the DS3231
 *  - Echo the value from the DS3231 during 5 seconds
 *****************************************************************************************************/
void loop() {
  // If something is coming in on the serial line, it's
  // a time correction so set the clock accordingly.
  /*
  if (Serial.available()) {
    inputDateFromSerial();

    myRTC.setClockMode(false);  // set to 24h

    myRTC.setYear(year);
    myRTC.setMonth(month);
    myRTC.setDate(date);
    myRTC.setDoW(dow);
    myRTC.setHour(hour);
    myRTC.setMinute(minute);
    myRTC.setSecond(second);
*/
    // Give time at next five seconds
    for (uint8_t i = 0; i < 30; i++){
        delay(1000);
        Serial.print(myRTC.getYear(), DEC);
        Serial.print("-");
        Serial.print(myRTC.getMonth(century), DEC);
        Serial.print("-");
        Serial.print(myRTC.getDate(), DEC);
        Serial.print(" ");
        Serial.print(myRTC.getHour(h12Flag, pmFlag), DEC); //24-hr
        Serial.print(":");
        Serial.print(myRTC.getMinute(), DEC);
        Serial.print(":");
        Serial.println(myRTC.getSecond(), DEC);
        int seco=myRTC.getSecond();
        nixieDrive(0,seco %10);
    }

    // Notify that we are ready for the next input
    Serial.println("Please enter the current time to set on DS3231 ended by 'x':");
  
  delay(1000);
}

/*****************************************************************************************************
 * inputDateFromSerial
 *  - Read and interpret the data from the Serial input
 *  - Store the data in global variables
 *****************************************************************************************************/
void inputDateFromSerial() {
	// Call this if you notice something coming in on
	// the serial port. The stuff coming in should be in
	// the order YYMMDDwHHMMSS, with an 'x' at the end.
	boolean isStrComplete = false;
	char inputChar;
	byte temp1, temp2;
	char inputStr[20];

	uint8_t currentPos = 0;
	while (!isStrComplete) {
		if (Serial.available()) {
			inputChar = Serial.read();
			inputStr[currentPos] = inputChar;
			currentPos += 1;

      // Check if string complete (end with "x")
			if (inputChar == 'x') {
				isStrComplete = true;
			}
		}
	}
	Serial.println(inputStr);

  // Find the end of char "x"
  int posX = -1;
  for(uint8_t i = 0; i < 20; i++) {
    if(inputStr[i] == 'x') {
      posX = i;
      break;
    }
  }

  // Consider 0 character in ASCII
  uint8_t zeroAscii = '0';

	// Read Year first
	temp1 = (byte)inputStr[posX - 13] - zeroAscii;
	temp2 = (byte)inputStr[posX - 12] - zeroAscii;
	year = temp1 * 10 + temp2;

	// now month
	temp1 = (byte)inputStr[posX - 11] - zeroAscii;
	temp2 = (byte)inputStr[posX - 10] - zeroAscii;
	month = temp1 * 10 + temp2;

	// now date
	temp1 = (byte)inputStr[posX - 9] - zeroAscii;
	temp2 = (byte)inputStr[posX - 8] - zeroAscii;
	date = temp1 * 10 + temp2;

	// now Day of Week
	dow = (byte)inputStr[posX - 7] - zeroAscii;

	// now Hour
	temp1 = (byte)inputStr[posX - 6] - zeroAscii;
	temp2 = (byte)inputStr[posX - 5] - zeroAscii;
	hour = temp1 * 10 + temp2;

	// now Minute
	temp1 = (byte)inputStr[posX - 4] - zeroAscii;
	temp2 = (byte)inputStr[posX - 3] - zeroAscii;
	minute = temp1 * 10 + temp2;

	// now Second
	temp1 = (byte)inputStr[posX - 2] - zeroAscii;
	temp2 = (byte)inputStr[posX - 1] - zeroAscii;
	second = temp1 * 10 + temp2;
}

void nixieDrive(int tubeNumber, int tubeValue) {
  // Set the segment pins to display the number
  for (int j = 0; j < 4; j++) {
    // Determine whether the current segment should be on or off based on the number
    boolean segmentState = segments[tubeValue][j];
    digitalWrite(segmentPins[tubeNumber][j], segmentState);
 
  }
}

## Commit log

2021-10-05 First steps
    [nixieClock.PrjPcb, nixieClockSchematic.SchDoc, tokgoz.PcbLib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]
2023-09-21 ordered nixie pcb first version
    [BOM_20230921.csv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]
2024-06-29 signal stage pcb ordered
    [BOM_Power_Stage_20230921.csv, BOM_Signal_Stage__20240629.csv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]
